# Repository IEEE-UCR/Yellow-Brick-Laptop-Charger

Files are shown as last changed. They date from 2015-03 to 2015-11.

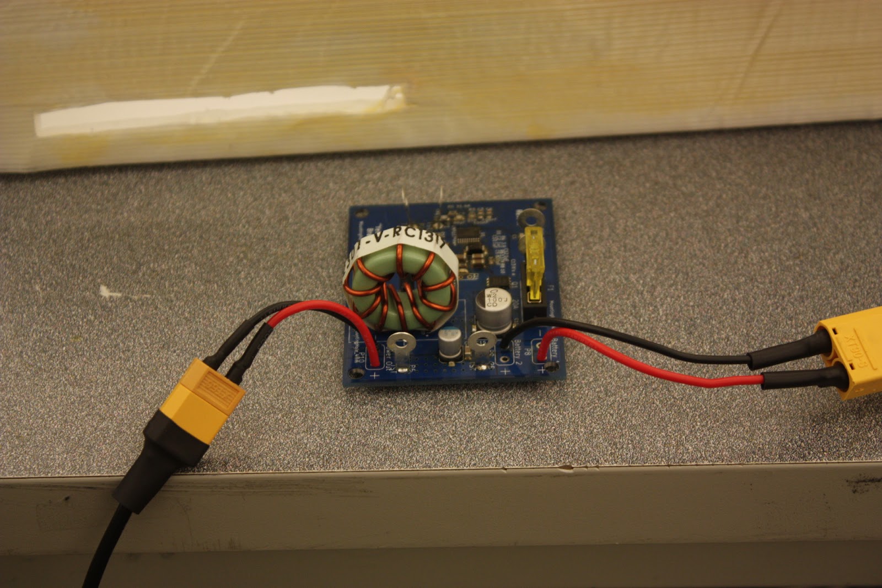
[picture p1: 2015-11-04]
testing_brick.jpg

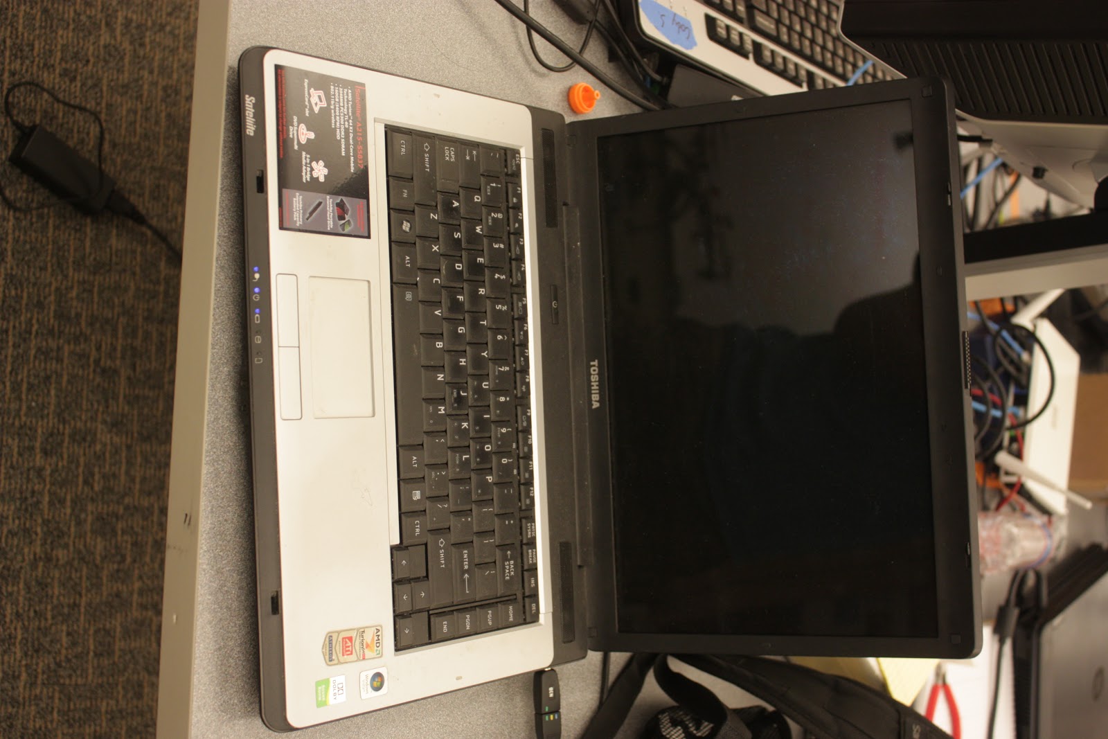
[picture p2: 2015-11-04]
brick_tester.JPG

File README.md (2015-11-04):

Yellow-Brick-Laptop-Charger
===========================

Because why not charge your laptop from a giant, scary yellow brick lipo?

Made with KiCAD nightly.

Design Specifics
----------------
The most important things (the soft start and such are all set to the Ti
reference values) are the UVLO and output voltage divider.

The UVLO circuit is set to around 36V (3.0V per cell in a 12S configuration).
It is noted that paranoid users can use a 10S lipo (which would cut off at
around 3.6V per cell).

The output voltage divider is set at 19V.  This is enough to power most devices.  It is crucial that a 5V buck converter be added for USB devices (or else they
might blow up.)

BOM
---
The Bill of Materials is actually pretty hard to generate from the nightly
version of kicad that Brandon is running.
So, the XML file actually has all of the materials in it.
Most of the components are 0805 sized, except for the 1μF capacitors which are
(and don't quote me on this) 1206 sized.

Here is a Digi-key link for enough parts to prototype three of these boards.
http://www.digikey.com/short/749jqc  These include the test points.  Feel
free to modify things as fit.  Do note that these BOMs do not contain the
LEDs for indicating that the board is powered.  (Or at least I don't think
they do...)

PCB
---
There is a dirty PCBs order that I placed a while ago.
Here is the "share" link.
http://dirtypcbs.com/view.php?share=4775&accesskey=4ce9e3b627f7e16a034119993f725ab9

You should be able to order the protopack pretty easily through this link.
Beware that these may not be the most current PCBs.

Important Notes
---------------
There are some specific packages that are not included in the KiCAD libraries,
but all of those should be included within this package.

Note that this.pretty contains component footprints associated to this build.
Note that the schematic symbols associated with this build aren't very neatly
organized in a separate folder.

The inductor specified in the Digikey order is not entirely correct.  The design (later on) was used with a T106-2 core from Micrometals with the appropriate number of turns.  Use an online calculator.

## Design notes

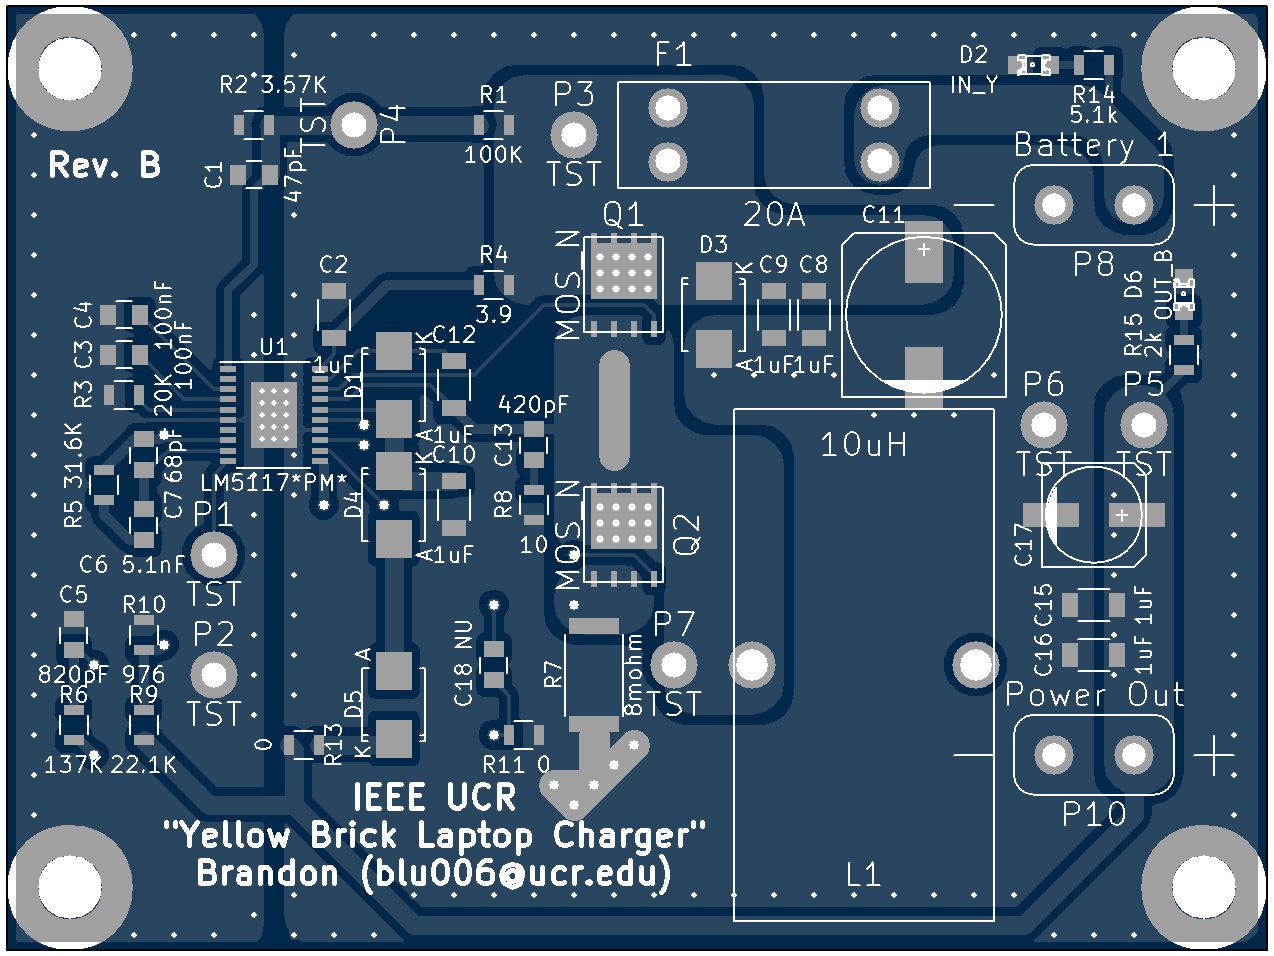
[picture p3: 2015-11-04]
pcb_top.png

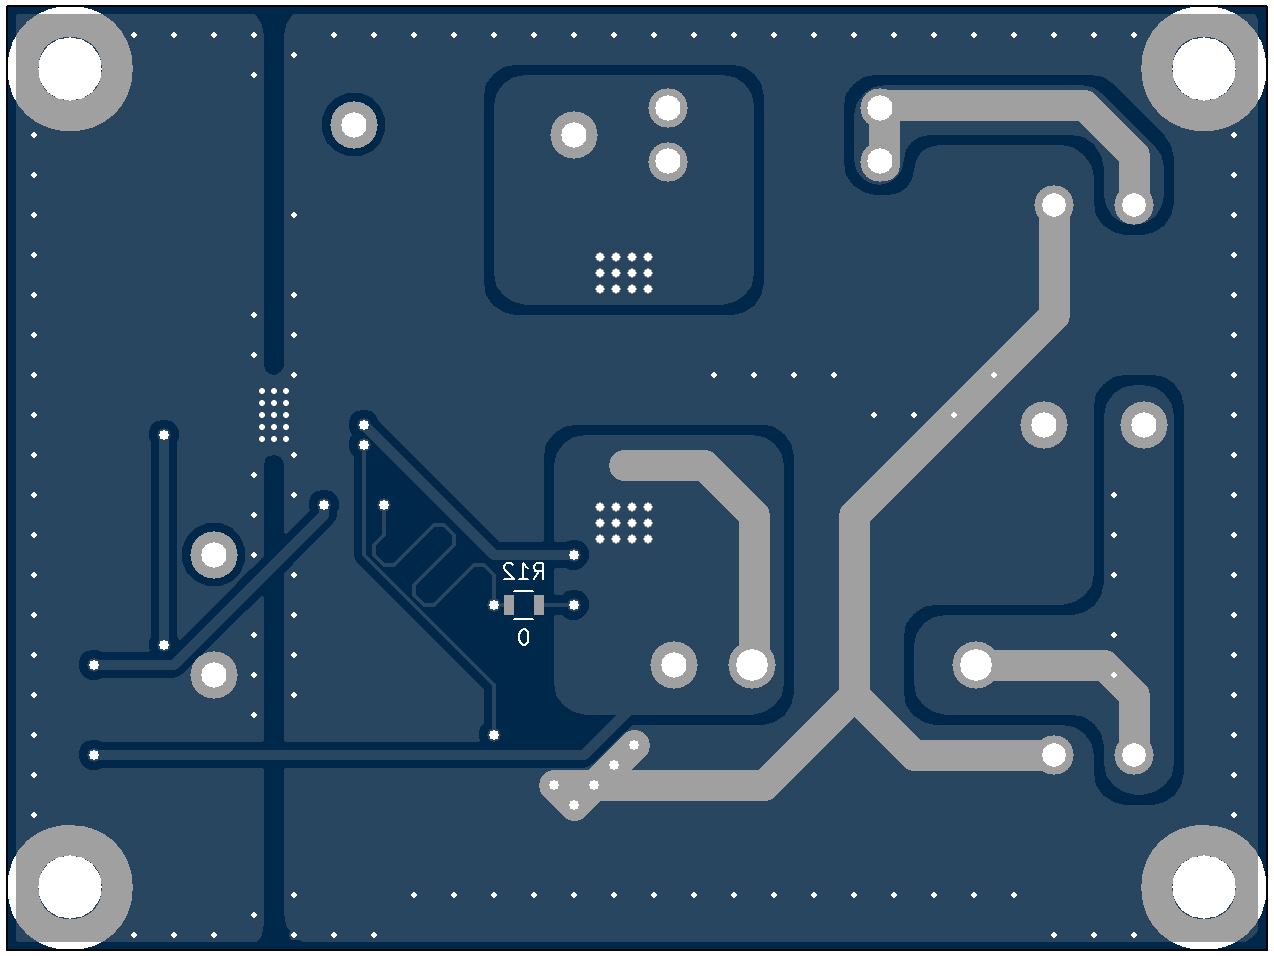
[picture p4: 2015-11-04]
pcb_bottom.png

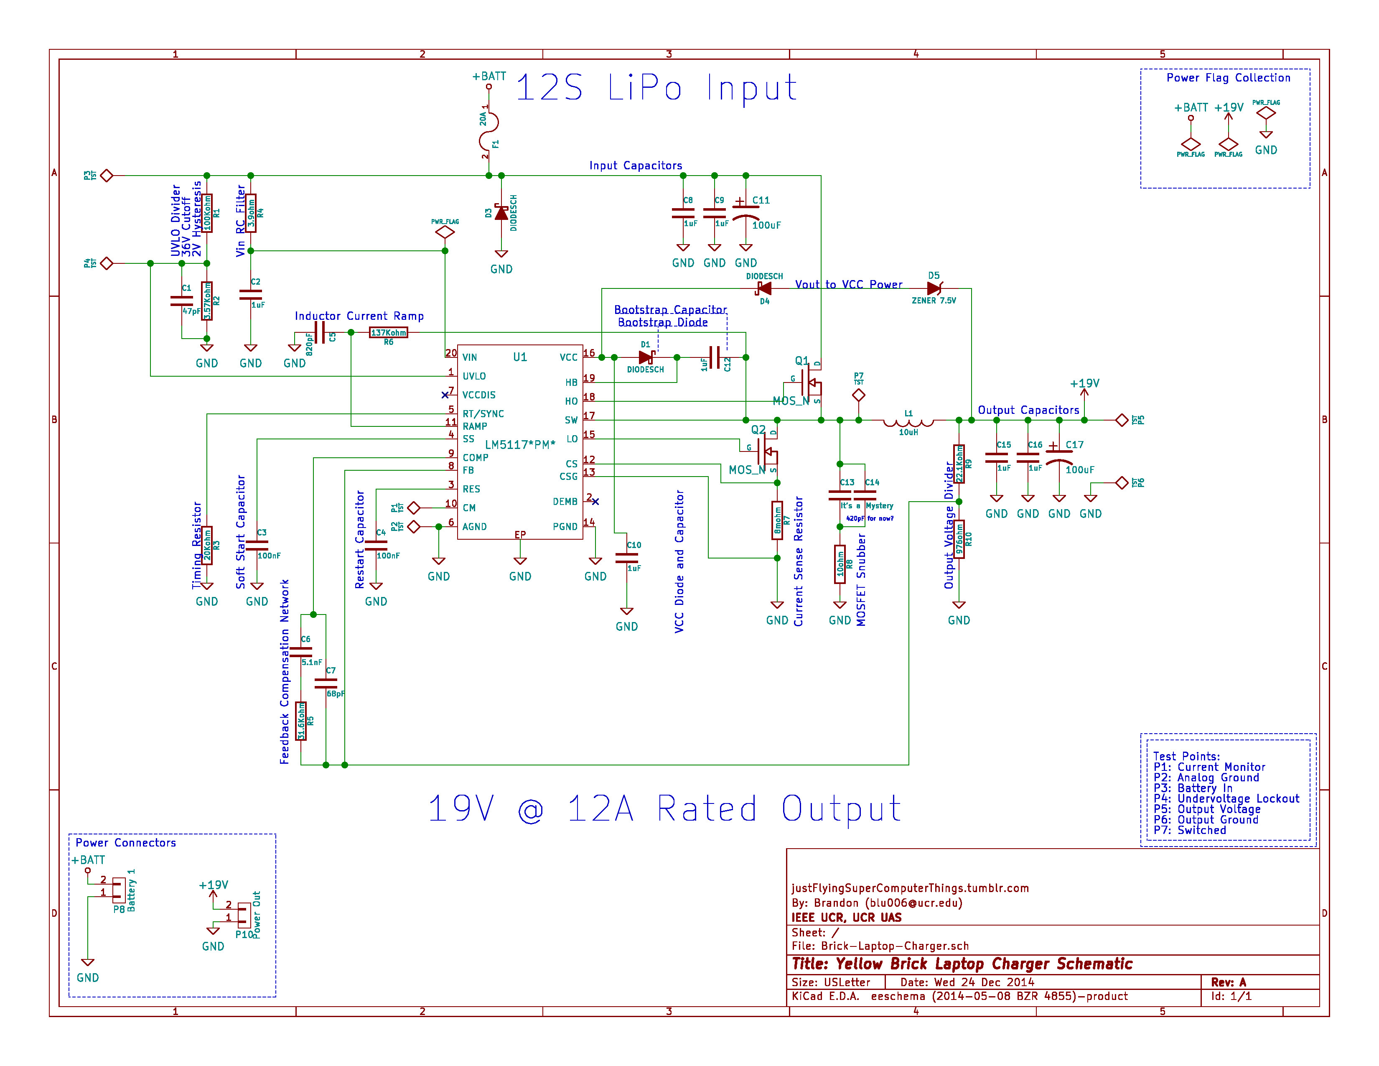
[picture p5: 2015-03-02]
Brick-Laptop-Charger.jpg

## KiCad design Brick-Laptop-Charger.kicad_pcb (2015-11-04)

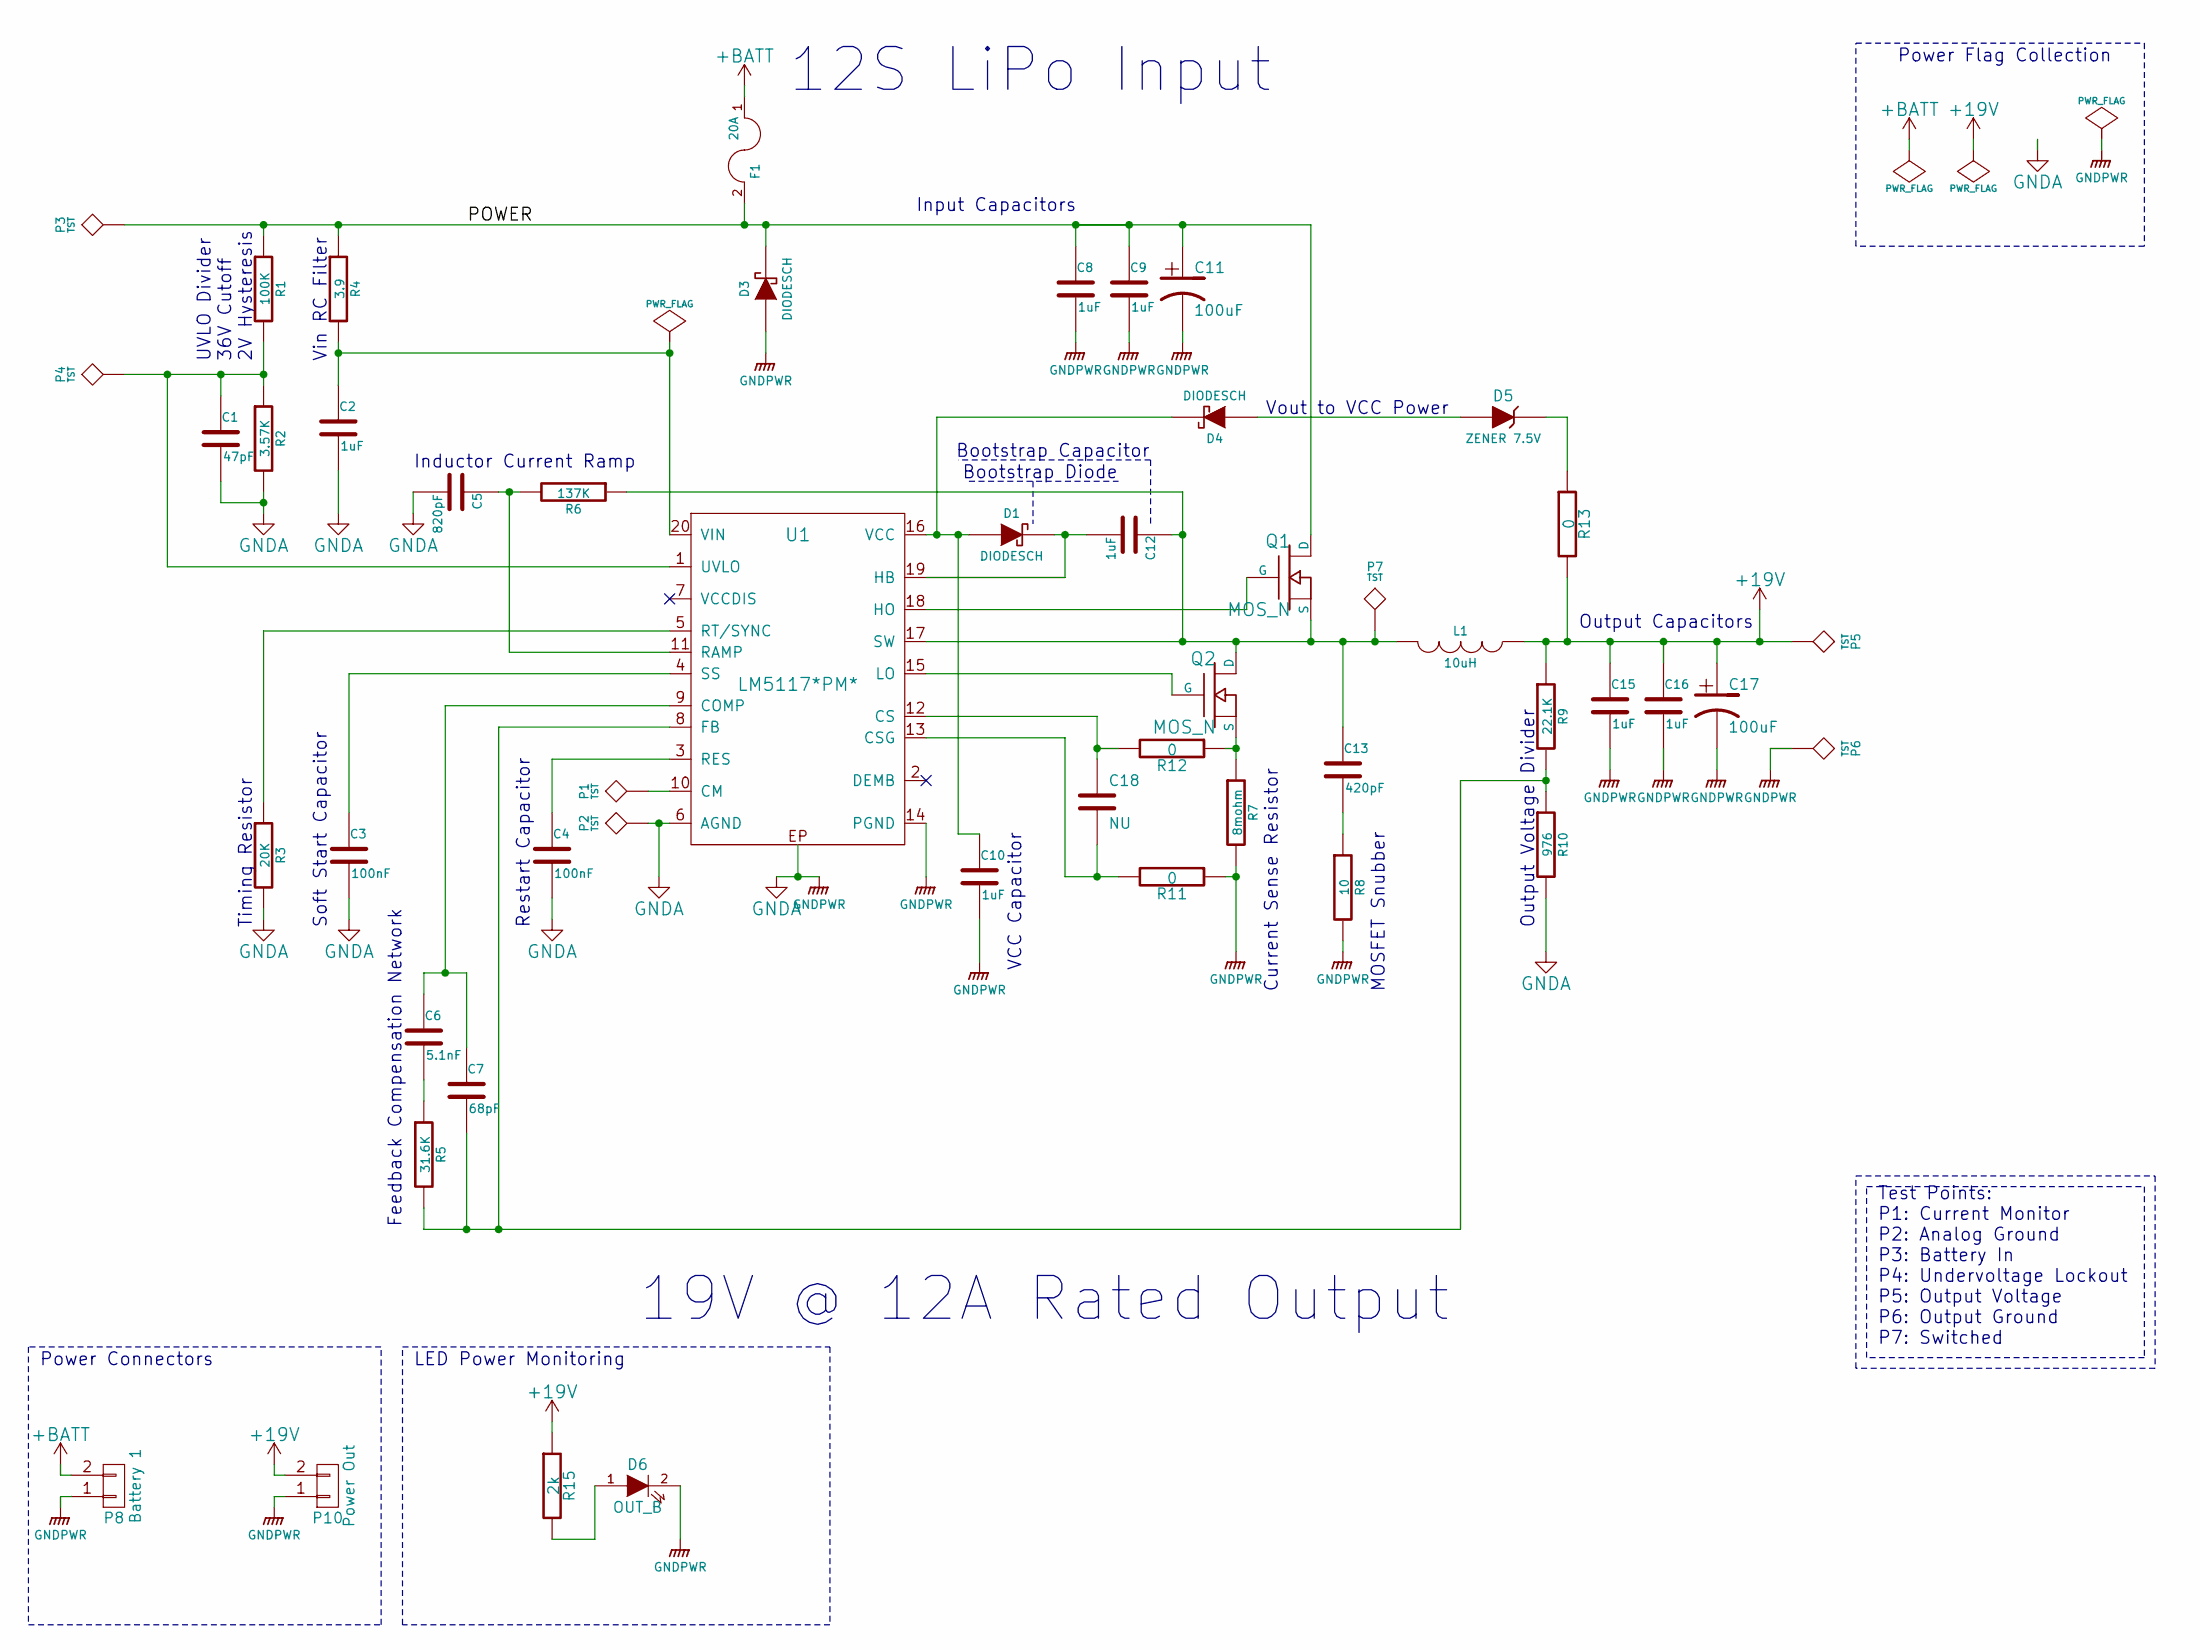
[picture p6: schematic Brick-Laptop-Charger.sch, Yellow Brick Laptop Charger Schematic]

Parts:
C1: 47pF; C_0805
C2, C8, C9, C10, C12, C15, C16: 1uF; C_1206
C3, C4: 100nF; C_0805
C5: 820pF; C_0805
C6: 5.1nF; C_0805
C7: 68pF; C_0805
C11: 100uF; c_elec_10x10
C13: 420pF; C_0805
C17: 100uF; c_elec_6.3x7.7
C18: NU; C_0805
D1, D3, D4: DIODESCH; Diode-SMB_Standard
D5: ZENER 7.5V; Diode-SMB_Standard
D6: OUT_B; LED-0805
F1: 20A; PC_Auto_Fuse_Holder
L1: 10uH; Toroidal
P1, P2, P3, P4, P5, P6, P7: TST; TP
P8: Battery 1; BIG_CONN
P10: Power Out; BIG_CONN
Q1, Q2: MOS_N; PQFN-8-GDS_IRF_B_5mmx6mm
R1: 100K; R_0805
R2: 3.57K; R_0805
R3: 20K; R_0805
R4: 3.9; R_0805
R5: 31.6K; R_0805
R6: 137K; R_0805
R7: 8mohm; R_2512
R8: 10; R_0805
R9: 22.1K; R_0805
R10: 976; R_0805
R11, R12, R13: 0; R_0805
R15: 2k; R_0805
U1: LM5117*PM*; SSOP-20-1EP_4.4x6.5mm_Pitch0.65mm

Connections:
+19V: C15.1, C16.1, C17.1, L1.1, P5.1, P10.2, R9.1, R13.2, R15.1
+BATT: F1.1, P8.2
/POWER: C8.1, C9.1, C11.1, D3.2 (K), F1.2, P3.1, Q1.D, R1.1, R4.1; also elsewhere on the board
GNDA: C1.2, C2.2, C3.2, C4.2, C5.2, C8.2, C9.2, C10.2, C11.2, C15.2, C16.2, C17.2, D3.1 (A), D6.2 (K), P2.1, P6.1, P8.1, P10.1, R2.2, R3.2, R7.2, R8.2, R10.2, R11.1, U1.6 (AGND), U1.14 (PGND), U1.EP; also elsewhere on the board
unnamed: C1.1, P4.1, R1.2, R2.1, U1.1 (UVLO)
unnamed: C2.1, R4.2, U1.20 (VIN)
unnamed: C3.1, U1.4 (SS)
unnamed: C4.1, U1.3 (RES)
unnamed: C5.1, R6.2, U1.11 (RAMP)
unnamed: C6.1, C7.1, U1.9 (COMP)
unnamed: C6.2, R5.1
unnamed: C7.2, R5.2, R9.2, R10.1, U1.8 (FB)
unnamed: C10.1, D1.1 (A), D4.2 (K), U1.16 (VCC)
unnamed: C12.1, C13.1, L1.2, P7.1, Q1.S, Q2.D, R6.1, U1.17 (SW)
unnamed: C12.2, D1.2 (K), U1.19 (HB)
unnamed: C13.2, R8.1
unnamed: C18.1, R12.2, U1.12 (CS)
unnamed: C18.2, R11.2, U1.13 (CSG)
unnamed: D4.1 (A), D5.1 (A)
unnamed: D5.2 (K), R13.1
unnamed: D6.1 (A), R15.2
unnamed: P1.1, U1.10 (CM)
unnamed: Q1.G, U1.18 (HO)
unnamed: Q2.G, U1.15 (LO)
unnamed: Q2.S, R7.1, R12.1
unnamed: R3.1, U1.5 (RT/SYNC)

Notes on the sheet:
MOSFET Snubber
Current Sense Resistor
UVLO Divider 36V Cutoff 2V Hysteresis
Vin RC Filter
Inductor Current Ramp
Timing Resistor
Soft Start Capacitor
Restart Capacitor
Bootstrap Capacitor
Bootstrap Diode
Output Voltage Divider
Feedback Compensation Network
VCC Capacitor
Power Flag Collection
Power Connectors
Test Points: P1: Current Monitor P2: Analog Ground P3: Battery In P4: Undervoltage Lockout P5: Output Voltage P6: Output Ground P7: Switched
Input Capacitors
Output Capacitors
Vout to VCC Power
19V @ 12A Rated Output
12S LiPo Input
LED Power Monitoring

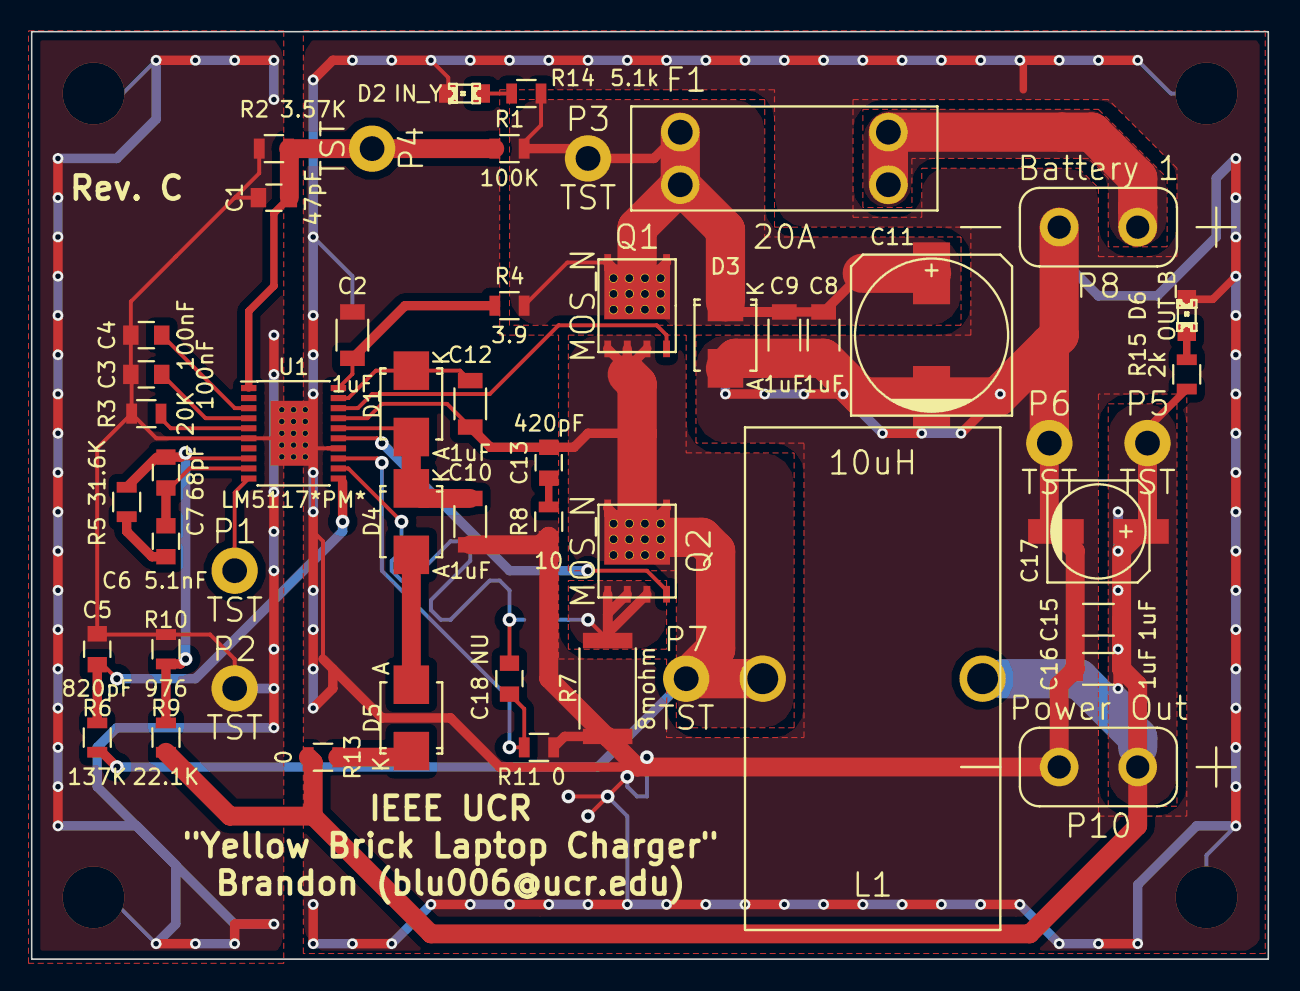
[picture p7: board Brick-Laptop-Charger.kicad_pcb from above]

Board: 2 copper layers, 80.0 x 60.0 mm, 52 parts (1 on the bottom side), 27 nets.

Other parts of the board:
D2: IN_Y; LED-0805
R14: 5.1k; R_0805

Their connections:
/POWER: R14.1; also elsewhere on the board
GNDA: D2.2; also elsewhere on the board
unnamed: D2.1, R14.2

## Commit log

2015-01-06 Added everything.
    [Brick-Laptop-Charger.kicad_pcb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]
2015-03-02 Separated analog and power grounds. Most of power current now flows through a separate path from analog circuitry (see exposed trace on bottom of PCB). Reduced capacitive coupling between ground plan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
    [Brick-Laptop-Charger-B_Cu.gbl, Brick-Laptop-Charger-B_Mask.gbs, Brick-Laptop-Charger-B_SilkS.gbo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]
2015-04-01 Modified readme file to current status.
2015-11-04 Moved files, removed backup files, added important notes about inductor selection, added images
    [Brick-Laptop-Charger.kicad_pcb, Brick-Laptop-Charger.sch]
